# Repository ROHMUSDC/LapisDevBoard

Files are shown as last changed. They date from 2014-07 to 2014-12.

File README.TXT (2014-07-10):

LAPIS DEV BOARD READ ME FILE
Last Updated 7 April 2014

Your New LAPIS Development Board comes pre-loaded with the firmware to allow communication between the custom GUI (Graphical User Interface) and your computer. 
This will allow you to control the state of the I/O pins on the LAPIS DEV BOARD.

Before starting, please review the following:
	1.) 	Read and review this document, and related ReadMe files in each of the sub directories
	2.) 	Read "Introduction to the LAPIS DEV BOARD.pdf" in this same directory
	3.) 	Read the Manual for the LAPIS DEV BOARD, as well as the Manual for the GUI (again, both are in this same directory)
	4.)	Review the manuals for the U8 Development Suite - Becoming familiar with this great suite of tools will be essential to getting the most 
		 out of your LAPIS DEV BOARD! (See: folder titled: "Manuals for the U8 Development Suite")

START UP GUIDE:
	1.)	Install U8 Development Suite on your computer 
		Installation includes “C” compiler, Debugger, Flash Programmer – used to write application code and debug its operation
		Installation also includes all the software manuals for the U8 Development tools
	2.)	Once U8 Development Suite is installed, connect your LAPIS DEV BOARD to your Computer via supplied USB Cable
	3.)	If FTDI drivers need installed to help computer connect to LAPIS DEV BOARD, please do so now. (See Read Me File in FTDI Virtual Com Port Drivers directory)
	4.)	Run the GUI, "LAPIS DEV BOARD_ControlSoftware_3-31-2014_rev01.exe" found in the folder: GUI Program 
	5.) 	Select your COM PORT and click the OPEN PORT Button in the GUI
	6.) 	Click "Test UART" Button in the GUI - The Console Window should now state that the LAPIS DEV BOARD ML610Q112 is connected to your computer

LAPIS DEV BOARD Disk FILE CONTENTS:
	1.) U8 Development Suite Installation CD image - (Compiler, IDE, Debugger, LAPIS U8 Manuals, etc.)
	2.) Data Sheets - Links to download latest Data Sheets
	3.) Express PCB Universal Socket Example - An example of an add-on board for the LAPIS DEV BOARD Platform - 
		Can be used to create custom Plug 'n Play boards for your LAPIS DEV BOARD.
	4.) FTDI Virtual Com Port Drivers - Driver may be needed to allow your LAPIS DEV BOARD to communicate with your Computer. They can be found here if needed.
	5.) GUI Program - Custom Graphical User Interface by Kris Bahar to allow communication between your LAPIS DEV BOARD and your Computer.
	6.) LAPIS DEV BOARD Design Files - Schematics, Board Layout Files, Gerber Files, Bill of Materials, etc. for the LAPIS DEV BOARD
	7.) Pictures for LAPIS DEV BOARD Manual - Various pictures used in LAPIS DEV BOARD Manuals
	8.) SAMPLE Code - Development Code for the LAPIS Semiconductor ML610Q111 & ML610Q112 microcontrollers 
		that can be tested out on this Development Board and to help develop your own applications
		a.) Q111 - 3COLOR_LED_LIGHTING
		b.) Q111 - Quad_Encod_PWM
		c.) Q111 - TEMPLATE
		d.) Q112 - 3COLOR_LED_LIGHTING
		e.) Q112 - Analog
		f.) Q112 - GPIO Complete
		g.) Q112 - PIR ALARM
		h.) Q112 - Quad_Encod_PWM
		i.) Q112 - TEMPLATE
		j.) Q178 - LED_LIGHTING
		k.) UART PAIR (Q111 to Q112 at 512k) (Connect RX of Q111 to TX of Q112 & TX of Q111 to RX of Q112 via 22ohm resistors)
	9.) LAPIS DEV BOARD User Manual (LAPIS DEV BOARD User Manual - Rev 2.7.pdf)
       10.) LAPIS DEV BOARD GUI Manual (LAPIS DEV BOARD GUI Manual - Rev 1.0.pdf)
       11.) Misc. - Contains miscellaneous, LAPIS files.
       12.) Documents:
		a.) Introduction to the LAPIS DEV BOARD.pdf
		b.) Out of Box Guide.pdf
		c.) LAPIS DEV BOARD User Manual - Rev 2.7.pdf
		d.) LAPIS DEV BOARD GUI Manual - Rev 1.0.pdf
		e.) LAPIS DEV BOARD READ ME FILE.TXT

Please contact Carl Schell (cschell@rohmsemiconductor.com) and Alec Melnick (amelnick@rohmsemiconductor.com) for help, support or questions regarding this LAPIS DEV BOARD Kit.

Good Luck in your designs!

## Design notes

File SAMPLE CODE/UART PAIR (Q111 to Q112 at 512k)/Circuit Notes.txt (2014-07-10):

//Circuit Notes:

//Because your LaPi Development Board has 2 independent micros on it, you can easily 
//connect them together and utilize both at the same time!
//
//You will want to connect the TX pin of one micro (say the Q111) to the RX pin
//  of the other (Q112)...and likewise the RX pin of the first micro (Q111) to 
//  the TX of the second (Q112). You can do this on the prototyping area of the
//  LaPi Dev Board.  I put 330 resistors in series for each of the two connections
//  to limit the current.
//
//Once connected, program each micro with the communication code, and they are 
//  now able to communicate at very fast speeds. I had both micros running at
//  512,000 Baud, and communication was fine!

//In this example set, the Q111 micro (MASTER) sends data to the Q112 micro (SLAVE), so they
//are acting as MASTER & SLAVE...but there is no reason, there couldn't be 
//back-and-forth communication...

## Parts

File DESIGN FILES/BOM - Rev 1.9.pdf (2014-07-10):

## LaPi Development Board

CIRCUIT SCHEMATIC | Revision: 1.9
Last Updated | April 10th, 2013 - 17:30
# | Reference | Value | Footprint | Manufacturer | Manufacturer's Part # | Digi-Key Part#

1 | J2 | Voltage Selector | Through-hole - 1x3 | Samtec | HTSW-103-07-G-S | HTSW-103-07-G-S-ND
2 | J5 | Target Micro Selector - TST
3 | J6 | Target Micro Selector - RST
4 | J7 | nanoEase PWR Opt Selector
5 | J12 | MCU Com Selector - RX
6 | J13 | MCU Com Selector - TX
7 | J14 | nanoEase RST Opt Selector
8 | J8 | Debugger | Through-hole - 2x7 | Samtec | TSW-150-07-L-D | SAM1030-50-ND
9 | J9 | Universal Socket #1 | Through-hole - 2x13
10 | J10 | Universal Socket #2 | Through-hole - 2x13
11 | J11 | SMD - micro USB | Surface Mount - microUSB | Hirose | ZX62R-B-5P | H11574CT-ND
12 | J1 | External Power | xxx | xxx | xxx | xxx
13 | J3 | 15 I/O Pins Q111 | xxx | xxx | xxx | xxx
14 | J4 | 25 I/O pins Q112 | xxx | xxx | xxx | xxx
15 | U1 - New | 3.3v LDO Reg (USB 5V to 3.3v, etc.) | Surface Mount - HRP5 (5-pins plus tab) | ROHM | BA33D18HFP | BA33D18HFPDKR-ND
16 | U2 | Q111 - 5V, 8-Bit, 20-pin LAPIS Micro | Surface Mount - TSSOP-20 (20-pin) | ROHM | ML610Q111 | LAPIS-SAMPLES
17 | U3 | Q112 - 5V, 8-Bit, 20-pin LAPIS Micro | Surface Mount - LQFP-32 (32-pin) | ROHM | ML610Q112 | LAPIS-SAMPLES
18 | U4 | Voltage Level Shifter (2-bit) | Surface Mount - DCT (8-pin) | Texas Instruments | TXS0102DCTR | 296-21978-1-ND
19 | U5 | USB-to-UART Translator | Surface Mount - SSOP (16-pin) | FTDI | FT230XS-R | 768-1135-1-ND
20 | S1 - New | Micro's Reset Button (Normally Open) | Surface Mount (2-pad) | E-Switch | TL3302AF180QG | EG2528DKR-ND
21 | LED1 | RED - 5V PWR | SMD 0805 (2012 Metric) | ROHM | SML-210VTT86 | 511-1289-1-ND
22 | LED2 | RED - 3.3V PWR
23 | LED3 | GREEN - RX Indicator | SMD 0805 (2012 Metric) | ROHM | SML-210MTT86 | 511-1287-1-ND
24 | LED4 | YELLOW - TX Indicator | SMD 0805 (2012 Metric) | ROHM | SML-210YTT86 | 511-1290-1-ND
25 | D1 | Schottky Diode Input Protection - 20V 3A | Surface Mount - 123SOD (2-pads) | ROHM | RB051M-2YTR | RB051M-2YCT-ND (http://www.digikey.com/product-detail/en/RB051M-2YTR/RB051M-2YCT-ND/2615726)
26 | FB1 | Ferrite Bead (600R/0.5A) | SMD 0805 (2012 Metric) | Laird | MI0805K601R-10 | 240-2390-1-ND
27 | R1 | 0R | SMD 0805 (2012 Metric) | ROHM | MCR10EZPJ000 | RHM0.0ARCT-ND
28 | R2
29 | R3
30 | R4
31 | R14
32 | R15
33 | R16
34 | R17
35 | R23 | 27R | SMD 0805 (2012 Metric) | ROHM | MCR10EZPF2702 | RHM27.0KCRCT-ND
36 | R24
37 | R6 | 270R | SMD 0805 (2012 Metric) | ROHM | MCR10EZHJ271 | RHM270ACT-ND
38 | R7
39 | R13
40 | R21
41 | R22
42 | R9 | 10k | SMD 0805 (2012 Metric) | ROHM | MCR10EZPF1002 | RHM10.0KCRCT-ND
43 | R10
44 | R11
45 | R12
46 | R20
47 | R18
48 | R25 | 15K | SMD 0805 (2012 Metric) | ROHM | MCR10EZPF1502 | RHM15.0KCRCT-ND
49 | C16 | Cer - 47pF | SMD 0805 (2012 Metric) | Kemet | C0805C470J1GACTU | 399-8079-1-ND
50 | C17
51 | C1 | Cer - 0.01 µF | SMD 0805 (2012 Metric) | TDK Corporation | C2012X7R2E103K | 445-2280-1-ND
52 | C6
53 | C15
54 | C18
55 | C5 | Cer - 0.1 µF | SMD 0805 (2012 Metric) | TDK Corporation | C2012X7R2A104K | 445-1418-1-ND
56 | C10
57 | C11
58 | C13
59 | C14
60 | C19
61 | C3 - New | Polarized - 3.3 µF, 50V | SMD Alum Cap (660x773) | Panasonic | EEE-1HA3R3NP | PCE4303DKR-ND
62 | C12 | Polarized - 4.7 µF | SMD Alum Cap (430x540) | Panasonic | ECE-V1EA4R7SR | PCE3066CT-ND
63 | C2 | Cer - 4.7 µF | SMD 0805 (2012 Metric) | TDK Corporation | C2012Y5V1A475Z/1.25 | 445-1370-1-ND
64 | C7
65 | C4 - New | Cer - 10 µF | SMD 0805 (2012 Metric) | TDK Corporation | C2012X5R1C106K085AC | 445-7644-6-ND
66 | Rubber Feet | 5 per board | Stick-on Rubber Feet | 3M | SJ-5003 (white) | SJ5003-9-ND
67 | Chiclets | 7 per board | Chicle Jumpers with Tab | Sullins Connector Solutions | NPC02SXON-RC | S9341-ND

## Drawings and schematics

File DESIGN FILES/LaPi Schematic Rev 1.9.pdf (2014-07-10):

# INPUT POWER

## For 5.0V to Micro:

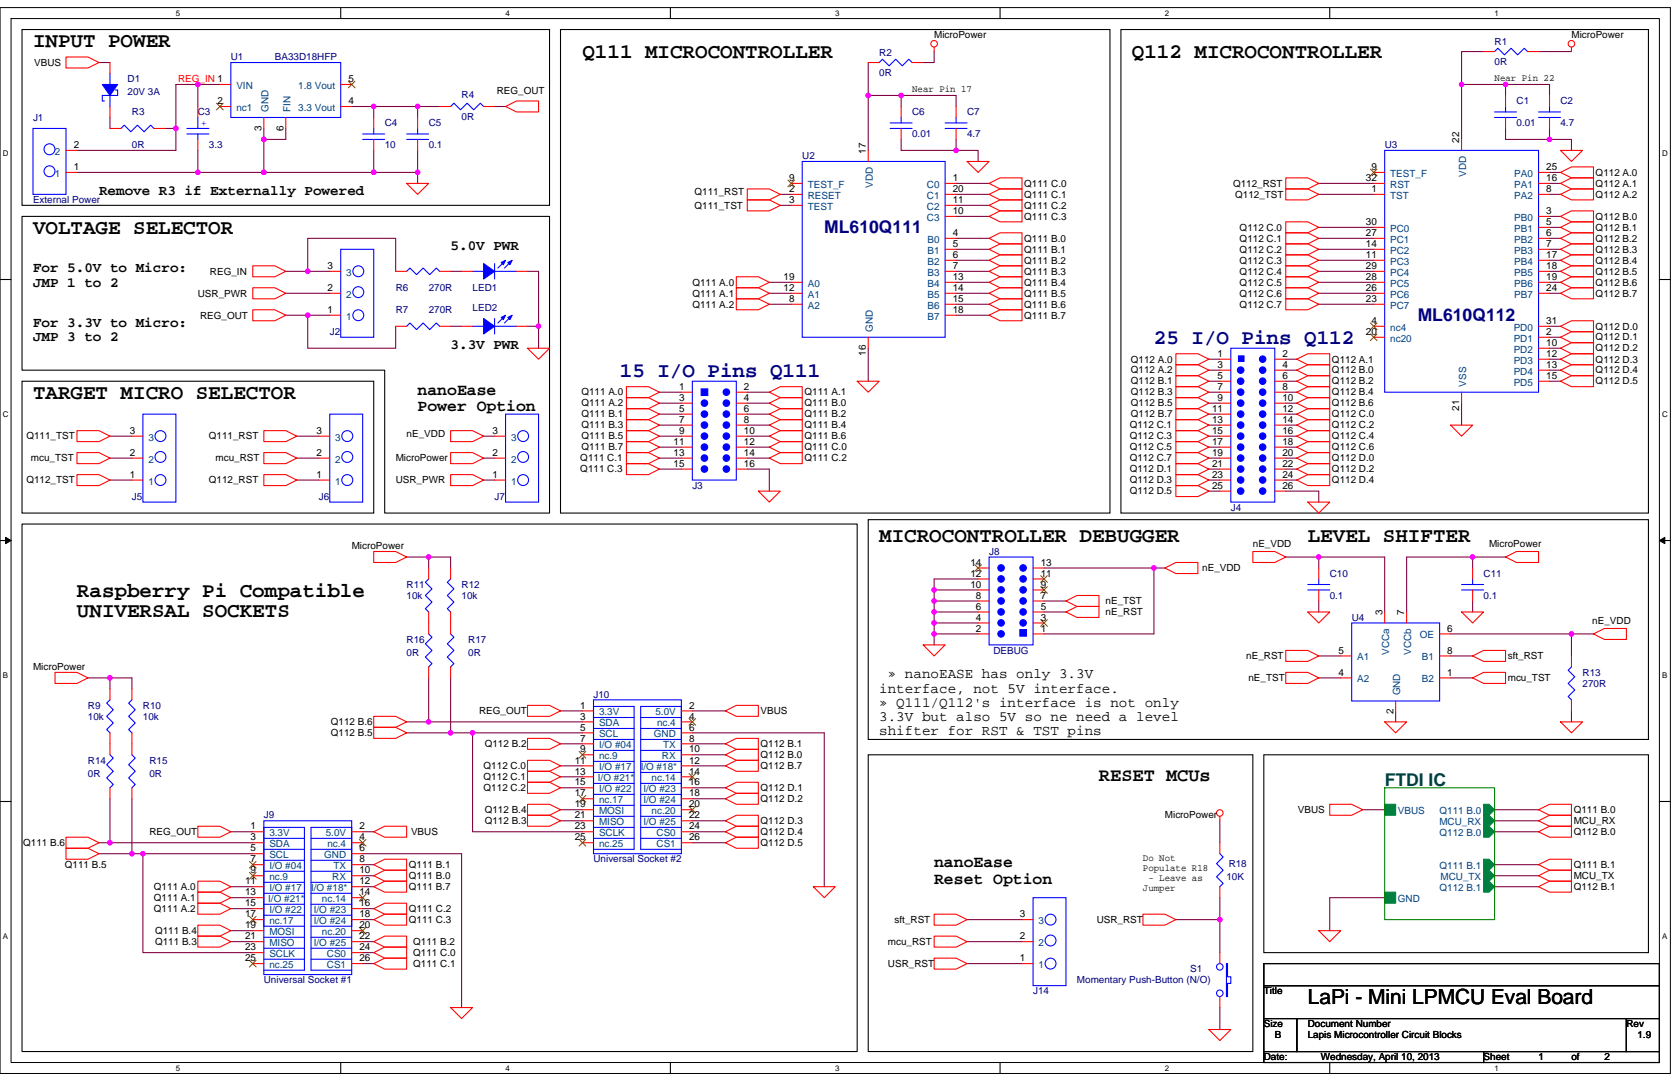
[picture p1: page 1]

Remove R3 if Externally Powered
VOLTAGE SELECTOR

» nanoEASE has only 3.3V
interface, not 5V interface.
» Q111/Q112's interface is not only
3.3V but also 5V so ne need a level
shifter for RST & TST pins

LaPi - Mini LPMCU Eval Board

Size Size Size B B B | Document Number Document Number Document Number Lapis Microcontroller Circuit Blocks Lapis Microcontroller Circuit Blocks Lapis Microcontroller Circuit Blocks | Rev Rev Rev 1.9 1.9 1.9

Date: Date: Date: Wednesday, April 10, 2013 Wednesday, April 10, 2013 Wednesday, April 10, 2013 | Sheet Sheet Sheet 1 1 1 of of of 2 2 2

# USB to serial UART interface

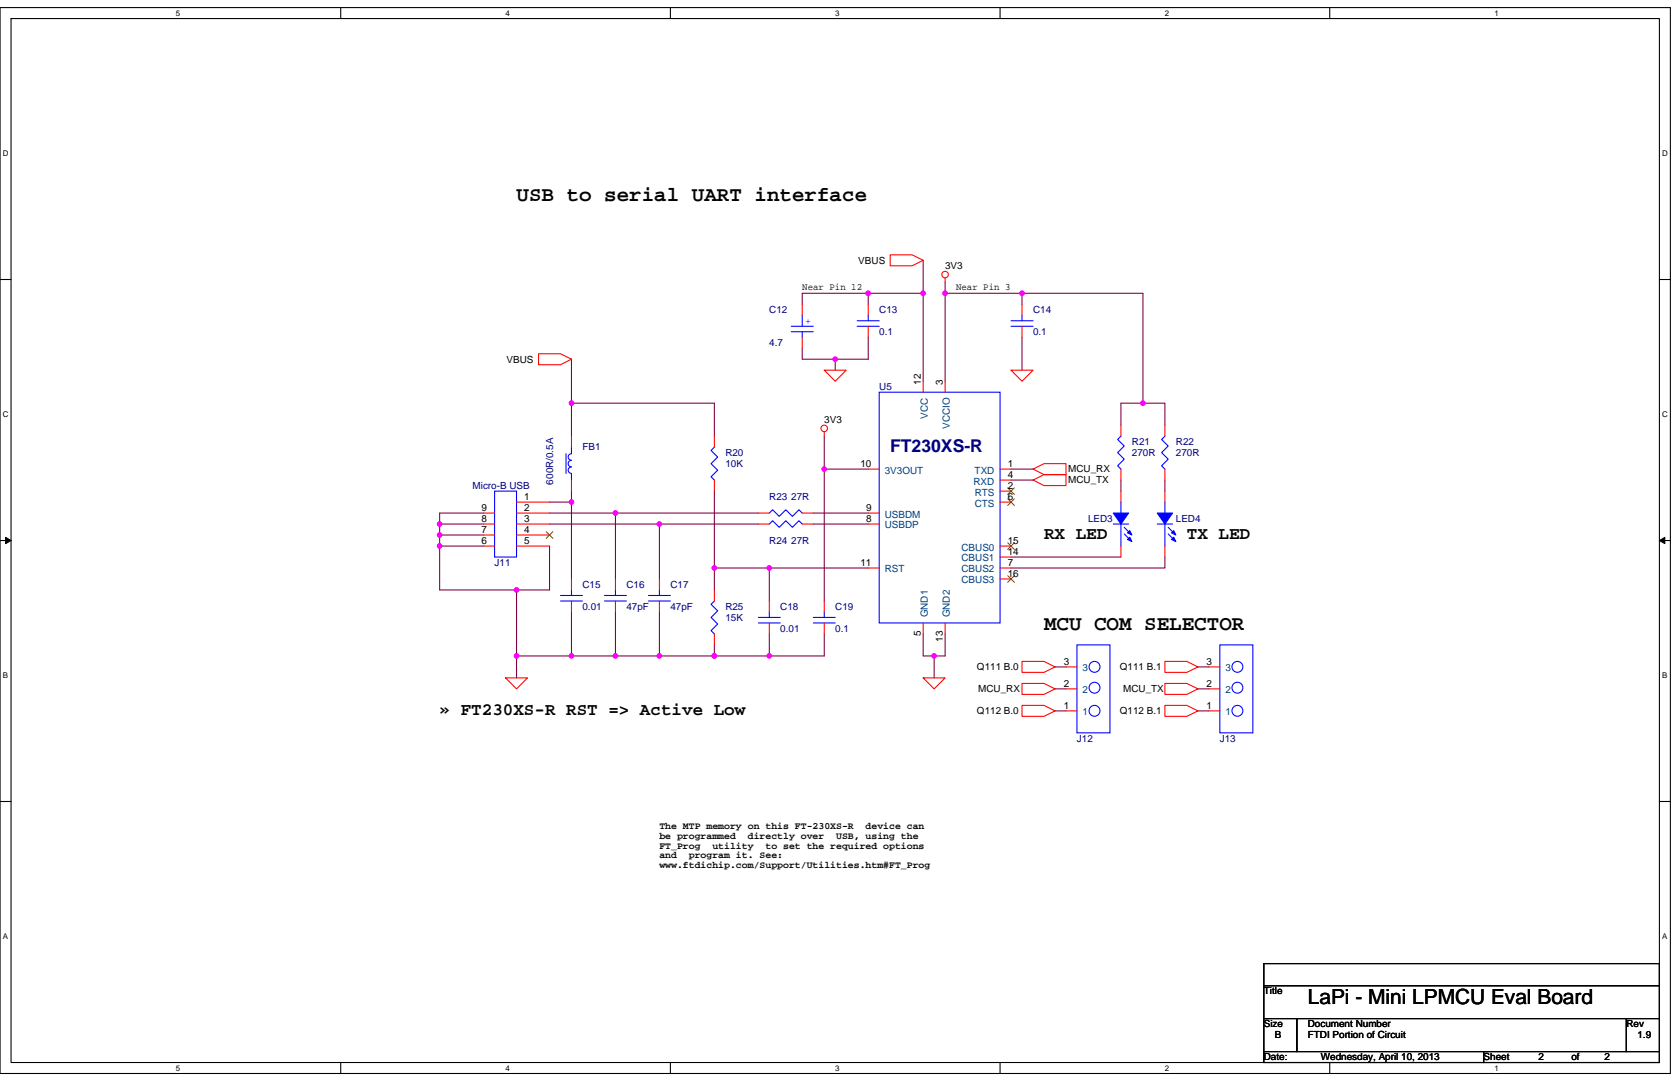
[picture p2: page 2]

The MTP memory on this FT-230XS-R device can
be programmed directly over USB, using the
FT_Prog utility to set the required options
and program it. See:
www.ftdichip.com/Support/Utilities.htm#FT_Prog

LaPi - Mini LPMCU Eval Board

Size Size Size B B B | Document Number Document Number Document Number FTDI Portion of Circuit FTDI Portion of Circuit FTDI Portion of Circuit | Rev Rev Rev 1.9 1.9 1.9

Date: Date: Date: Wednesday, April 10, 2013 Wednesday, April 10, 2013 Wednesday, April 10, 2013 | Sheet Sheet Sheet 2 2 2 of of of 2 2 2

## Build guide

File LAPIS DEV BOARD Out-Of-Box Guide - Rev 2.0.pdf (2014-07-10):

# LaPi Development Kit: “Out-Of-Box Guide”

## Introduction:

Thank you for purchasing our LaPi Development Kit. This LaPi kit will allow you to start creating your own applications using our powerful LAPIS microcontrollers (mcu). This board has 2 re-programmable mcu’s on it, each preprogrammed with firmware that will allow them to communicate out of the box with a simple Graphical User Interface (GUI) that we have developed. The GUI will allow you to plug your LaPi board into your computer over a USB interface, so that you can control any I/O pin on the device, including the UART, GPIOs, and I2C Bus controller.

Here are the 3 Steps to Install,

## Update and start using this system…

1.) Verify that the LaPi Evaluation Board is configured the way you need it.

2.) Review Documentation, Sample Code,
and other useful files on USB Flash
Drive - Connect the LaPi Dev Board to

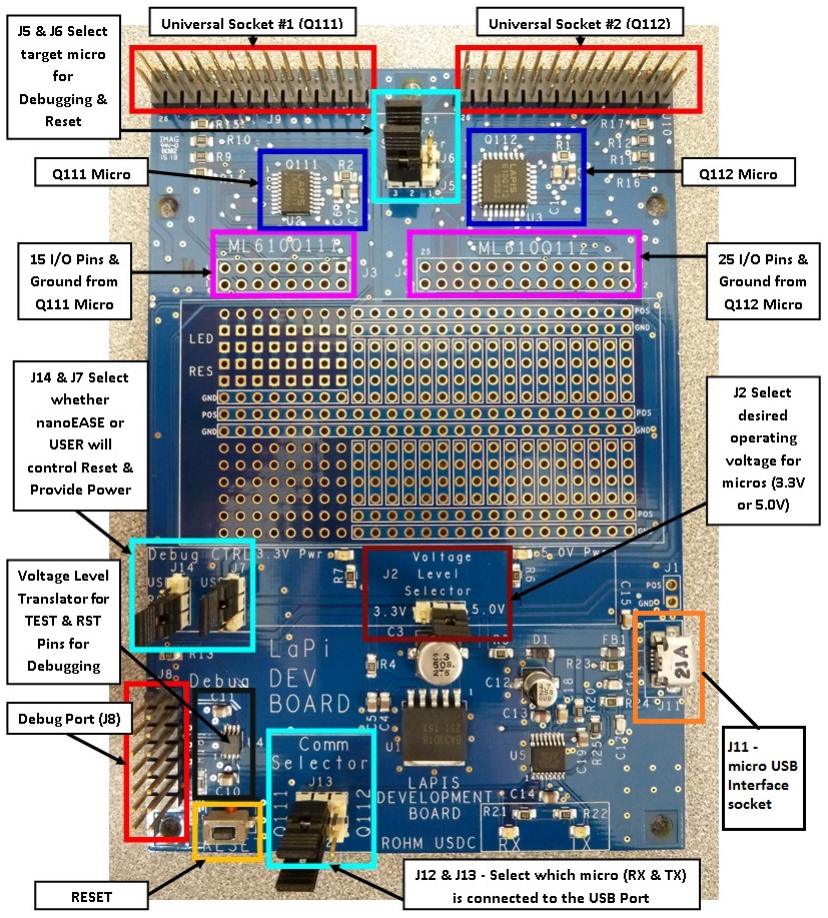
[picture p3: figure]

your computer using a USB cable. The drivers for the USB interface are located in the directory \FTDI Virtual Com Port Drivers. You should copy most of the files from the USB Flash drive to your computer. Run the windows program …\LaPi_StartingSoftware_REV01\LaPi - PC Application\LaPi_ControlSoftware_1-14-2014_rev01.exe to start the GUI communicating with the board. The programs on the mcus will operate with or without the debugger connected to the device.

3.) The code development tool used to write and debug code on the devices are provided on the USB FLASH Drive in the directory \U8 Dev Suite Install File. The tools run on Windows XP, Vista* and 7* (* = 32 (x32) bit or 64(x64) bit versions). You will have to log in as administrator to install in some of these environments.
Refer to Release Note-e.pdf for detailed install directions. To assure that you are using the latest tools register at the LAPIS Semiconductor Low Power Micro Support site: https://www.lapis-semi.com/customer/lpmcu/login.html

The projects that are preprogrammed on the ML610Q111 and 112 devices are located in the directory …\LaPi_StartingSoftware_REV01\LaPi - Q111 - Default Firmware (Release) and …\LaPi_StartingSoftware_REV01\Lapi - Q112 - Default Firmware (Release) respectively. Make sure that the project that you choose corresponds to the device that the GUI is connected to.

To see if new projects are available visit the LaPi Dev Kit section of http://www.rohm.com/web/global/lowpower-microcontroller (http://www.rohm.com/web/global/low-power-microcontroller) or contact LaPiDevKitSupport@rohmsemiconductor.com

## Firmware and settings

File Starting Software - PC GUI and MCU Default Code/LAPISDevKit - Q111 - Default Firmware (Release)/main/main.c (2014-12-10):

//*****************************************************************************
// Program:	 LAPIS Development Board Demo Code Q111
// Author:	 C. Schell & K. Bahar
//		 ROHM Semiconductor USA, LLC
//		 US Design Center
// Started:  April 6th, 2013
// Purpose:	 Demonstration Code for use with Lapis "LAPIS" Development Board 
// Updated:	 October 17th, 2013
//*****************************************************************************

//*****************************************************************************
// Microcontroller's connections on the LAPIS Development Board to the 
//  Plug 'n Play, Raspberry Pi Compatible, Universal Connectors:
//
// ================================ ML610Q111 ================================= 
//
// Pin-01 => 3.3V Power					Pin-02 => 5.0V Power (VBUS)
// Pin-03 => I2C-SDA  (Q111 I/O B.6)	Pin-04 => no connection
// Pin-05 => I2C-SCL  (Q111 I/O B.5)*	Pin-06 => GROUND
// Pin-07 => no connection*				Pin-08 => UART-TX  (Q111 I/O B.1)
// Pin-09 => no connection				Pin-10 => UART-RX  (Q111 I/O B.0) 
// Pin-11 => GPIO #17 (Q111 I/O A.0)	Pin-12 => GPIO #18 (Q111 I/O B.7)
// Pin-13 => GPIO #21 (Q111 I/O A.1)	Pin-14 => no connection
// Pin-15 => GPIO #22 (Q111 I/O A.2)	Pin-16 => GPIO #23 (Q111 I/O C.2)
// Pin-17 => no connection				Pin-18 => GPIO #24 (Q111 I/O C.3)
// Pin-19 => SPI-MOSI (Q111 I/O B.4)	Pin-20 => no connection
// Pin-21 => SPI-MISO (Q111 I/O B.3)	Pin-22 => GPIO #25 (Q111 I/O B.2)
// Pin-23 => SPI-SCLK (Q111 I/O B.5)*	Pin-24 => SPI-CS0  (Q111 I/O C.0)
// Pin-25 => no connection				Pin-26 => SPI-CS1  (Q111 I/O C.1)
//
//=============================================================================
//*****************************************************************************

//*****************************************************************************
// Q111 Microcontroller's I/O Pins at J3 on the LAPIS Development Board to the
// LAPIS Development Board 
//
// ================================ ML610Q111 ================================= 
//
// Pin-01 => A.0				Pin-02 => A.1
// Pin-03 => A.2				Pin-04 => B.0
// Pin-05 => B.1				Pin-06 => B.2
// Pin-07 => B.3				Pin-08 => B.4
// Pin-09 => B.5				Pin-10 => B.6 
// Pin-11 => B.7				Pin-12 => C.0
// Pin-13 => C.1				Pin-14 => C.2
// Pin-15 => C.3				Pin-16 => GROUND
//
//=============================================================================
//*****************************************************************************

//***** PREPROCESSOR DIRECTIVES ***********************************************
 // INCLUDED FILES...
	#include	<ML610111.H>	// Lapis Micro ML610Q111 on LAPIS Development Board
	//#include	<ctype.h>		// Character classification and conversion 
	//#include	<errno.h>		// Error identifiers Library
	//#include	<float.h>		// Numerical limits for floating-point numbers
	//#include	<limits.h>		// Numerical limits for integers
	//#include	<math.h>		// Mathematical functions
	//#include	<muldivu8.h>	// Multiplication and Division accelerator
	//#include	<setjmp.h>		// Global jump (longjmp)
	//#include	<signal.h>		// Signal handling functions
	//#include	<stdarg.h>		// Variable numbers of arguments
	//#include	<stddef.h>		// Standard types and macros 
	#include	<stdio.h>		// I/O-related processing
	#include	<stdlib.h>		// General-purpose utilities
	//#include	<string.h>		// Character string manipulation routines
	//#include	<yfuns.h>		// 
	//#include	<yvals.h>		// Called for by most Header Files
	#include 	<uart.h>		// UART Function Prototypes
	#include 	<common.h>		// Common Definitions
	#include 	<mcu.h>		// MCU Definition
	#include 	<irq.h>		// IRQ Definitions
	#include	"i2c.h"		// I2C Definition
	//#include 	<main.h>		// Clear WDT API
	//#include 	<clock.h>		// Set System Clock API
	//#include 	<tbc.h>		// Set TBC (Timer Based Clock) API
	//#include 	<timer.h>		// Timer Macros & APIs

//*****************************************************************************
 // I/O PIN DATA ALIASES...
// Connections for Q111 Universal Socket
	#define RX 		PB0D 
	#define TX 		PB1D
	#define I2C_SDA 	PB6D 
	#define I2C_SCL 	PB5D 
	#define GPIO_17	PA0D
	#define GPIO_21	PA1D
	#define GPIO_22	PA2D
	#define GPIO_18	PB7D
	#define GPIO_23	PC2D
	#define GPIO_24	PC3D
	#define GPIO_25	PB2D
	#define SPI_MOSI	PB4D
	#define SPI_MISO	PB3D
	#define SPI_SCL 	PB5D
	#define SPI_CS0		PC0D
	#define SPI_CS1 	PC1D 	

//*****************************************************************************
//===========================================================================
//   MACROS: 
//===========================================================================
// ===== Serial Strings =====
#define WelcomeString		( "LAPIS Q111 LAPIS DEV. DEMO") 
#define WelcomeString_LEN	( sizeof(WelcomeString) - 1 )

// ===== Peripheral setting.=====
#define HSCLK_KHZ	( 8000u )	// 8MHz = 8000kHz (will be multiplied by 1024 to give 8,192,000Hz)
#define FLG_SET	( 0x01u ) 

// ===== SET DESIRED UART SETTINGS HERE! (Options in UART.h) =====
	#define UART_BAUDRATE		( UART_BR_9600BPS) 	// Data Bits Per Second - Tested at rates from 2400bps to 512000bps!
	#define UART_DATA_LENGTH	( UART_LG_8BIT )		// x-Bit Data
	#define UART_PARITY_BIT		( UART_PT_NON )		// Parity
	#define UART_STOP_BIT		( UART_STP_1BIT )		// x Stop-Bits
	#define UART_LOGIC			( UART_NEG_POS )		// Desired Logic
	#define UART_DIRECTION		( UART_DIR_LSB )		// LSB or MSB First

//*****************************************************************************

//*****************************************************************************
//===========================================================================
//   STRUCTURES: 
//===========================================================================
//Example Structure Declaration
typedef struct {
	unsigned char state     : 1;
	unsigned char state_sub : 2;
	unsigned char reserve   : 5;
} STRUCT_STATE;	

static const tUartSetParam  _uartSetParam = {		// UART Parameters
	UART_BAUDRATE,						// Members of Structure...
	UART_DATA_LENGTH,						// Members of Structure...
	UART_PARITY_BIT,						// Members of Structure...
	UART_STOP_BIT,						// Members of Structure...
	UART_LOGIC,							// Members of Structure...
	UART_DIRECTION						// Members of Structure...
};

//*****************************************************************************


//*****************************************************************************
//===========================================================================
//   FUNCTION PROTOTYPES: 
//	Establishes the name and return type of a function and may specify the 
// 	types, formal parameter names and number of arguments to the function                                 
//===========================================================================
void main_clrWDT( void );			// no return value and no arguments
//void Alarm( void );				// no return value and no arguments
void Initialization( void );			// no return value and no arguments
void SetOSC( void );				// no return value and no arguments
void analog_comparator( void );		// no return value and no arguments
void PortA_Low( void );				// no return value and no arguments
void PortB_Low( void );				// no return value and no arguments
void PortC_Low( void );				// no return value and no arguments
void PortA_Digital_Inputs( void );		// no return value and no arguments
void PinB0_PWM( void ); 			// no return value and no arguments

void _funcUartFin( unsigned int size, unsigned char errStat );
void _funcI2CFin( unsigned int size, unsigned char errStat );
void checkI2C( void );
void main_reqNotHalt( void );
void _intUart( void );
void _intI2c( void );
void NOP1000( void );

//*****************************************************************************

//GLOBALS...
unsigned char	_flgUartFin;
unsigned char 	_flgI2CFin;
unsigned char	_reqNotHalt;

unsigned char	HelloWorld[14] = {"Hello World!  "};

unsigned char	InputStatus[23] = {"INP_00000000_00000000"};	//Used for Testing the UART Terminal during initial
unsigned char	InputRec[14] = {"INP Received"};				//Used for Testing the UART Terminal during initial
unsigned char	OutputRec[23] = {"OUT Received         "};		//Used for Testing the UART Terminal during initial
unsigned char	RecWorld[21];									//Used for Testing the UART Terminal during initial
unsigned char	AckMCUConn[22] = {"ML610Q111 Connected!"};
unsigned char	ListFWRev[22] = {"Firmware Version: 01"};
unsigned char	NackMCUConn[62] = {"Please Close Port and change Target MCU under Device Options"};
unsigned char	I2C_TX_REC[21] = {"I2CTX CMD Received!"};
unsigned char	I2C_RX_REC[21] = {"I2CRX CMD Received!"};
unsigned char	I2C_RX_Data[23] = {"I2C-R X X X X X X X X"};

unsigned int	UART_VAR;

static unsigned char			I2C_BUFF[46];
static unsigned char			I2CAdd;
static unsigned char			I2CNumBytes;
static unsigned char			Data0Str;
static unsigned char			Data1Str;
static unsigned char			Data2Str;
static unsigned char			Data3Str;
static unsigned char			Data4Str;
static unsigned char			Data5Str;
static unsigned char			Data6Str;
static unsigned char			Data7Str;
static unsigned char			RegAddr;
static unsigned char			I2CAdd_temp;
static unsigned char			I2CNumBytes_temp;
static unsigned char			Data0Str_temp;
static unsigned char			Data1Str_temp;
static unsigned char			Data2Str_temp;
static unsigned char			Data3Str_temp;
static unsigned char			Data4Str_temp;
static unsigned char			Data5Str_temp;
static unsigned char			Data6Str_temp;
static unsigned char			Data7Str_temp;
static unsigned char			RegAddr_temp;
static unsigned char			I2CSendInfo[8];
static unsigned char			I2CReceInfo[8];
static unsigned char			chari;
static unsigned char			charj;
static unsigned char			chark;

unsigned int ret;
unsigned int testI2C;

/*############################################################################*/
/*#                                  APIs                                    #*/
/*############################################################################*/
//*****************************************************************************
//===========================================================================
//  	Start of MAIN FUNCTION
//===========================================================================
int main(void) 
{

char char_a;			// -128 to 127
unsigned char uchar;		// 0-255
int inta, table [100];		// -32,768 to 32767
unsigned int uint;	// 0 to 65,535
long long_a, delay;			// -2,147,483,648 to 2,147,483,647
float float_a;			// 1.17549435e-38 to 3.40282347e+38
double double_a;			// 2.2250738585072014e-308 to 1.7976931348623157e+308 


//unsigned char encoder_position, previous_encoder_position;  // 0-255
unsigned char button_flag;  						// 0-255
int i,j,k,x,y;								// -32,768 to 32767
unsigned char sndByte;
unsigned int count;
char maskC;

Init:
	Initialization();		//Ports, UART, Timers, Oscillator, Comparators, etc.

RX_Loop:
		main_clrWDT();
		
		//Reset RecWorld for UART Receive
		for (i=0;i<22;i++)
		{
			RecWorld[i] = 0;	
		}
		
		//Begin UART Receive
		_flgUartFin = 0;
		uart_stop();
		uart_startReceive(RecWorld, 21, _funcUartFin);
		while(_flgUartFin != 1){
			NOP1000();
			main_clrWDT();
		}
		
		//Check UART Receive String for "ACK"
		//if ACK Sent, Return "UART Connected"
		//--This loop triggers when COM port is open3ed on PC
		if(RecWorld[0] == 0x41){			//if RECWORLD == "ACK1"
			if(RecWorld[1] == 0x43){
				if(RecWorld[2] == 0x4B){
					if(RecWorld[3] == 0x31){
						_flgUartFin = 0;
						uart_stop();
						uart_startSend(AckMCUConn, 22, _funcUartFin);
						while(_flgUartFin != 1){
							NOP1000();
							main_clrWDT();
						}
						_flgUartFin = 0;
						uart_stop();
						uart_startSend(ListFWRev, 22, _funcUartFin);
						while(_flgUartFin != 1){
							NOP1000();
							main_clrWDT();
						}
					}
					else
					{
						_flgUartFin = 0;
						uart_stop();
						uart_startSend(NackMCUConn, 62, _funcUartFin);
						while(_flgUartFin != 1){
							NOP1000();
							main_clrWDT();
						}
						
					}
				}
			}
		}
		
		//Check UART Receive String for "INC" - Input, Port C
		//This section is triggered by the GPIO command tab
		if(RecWorld[0] == 0x49){			//if RECWORLD == "INC"
			if(RecWorld[1] == 0x4E){
				if(RecWorld[2] == 0x43){
					InputStatus[2] = 0x43;
					InputRec[2] = 0x43;
					for(count = 4; count < 12; count++)
					{ 
						RecWorld[count] -= 0x30;
						if(RecWorld[count] != (0x01||0x00)){
							RecWorld[count] = 0;
						}
					}
					
					//Set PORTC to Input or Output based on PC application
					//PC7DIR = RecWorld[4];
					//PC6DIR = RecWorld[5];
					//PC5DIR = RecWorld[6];
					//PC4DIR = RecWorld[7];
					PC3DIR = RecWorld[8];
					PC2DIR = RecWorld[9];
					PC1DIR = RecWorld[10];
					PC0DIR = RecWorld[11];
					
					//Format I/O Direction into output string
					InputStatus[4] = 0x78;
					InputStatus[5] = 0x78;
					InputStatus[6] = 0x78;
					InputStatus[7] = 0x78;
					InputStatus[8] = PC3DIR + 0x30;
					InputStatus[9] = PC2DIR + 0x30;
					InputStatus[10] = PC1DIR + 0x30;
					InputStatus[11] = PC0DIR + 0x30;
					
					//Format I/O Level into output string
					InputStatus[13] = 0x78;
					InputStatus[14] = 0x78;
					InputStatus[15] = 0x78;
					InputStatus[16] = 0x78;
					InputStatus[17] = PC3D + 0x30;
					InputStatus[18] = PC2D + 0x30;
					InputStatus[19] = PC1D + 0x30;
					InputStatus[20] = PC0D + 0x30;
					
					//Send the InputStatus String
					//	"INP_[PC7DIR][PC6DIR]...[PC0DIR]_[PC7D]{PC6D]...[PC0D]"
					_flgUartFin = 0;
					uart_stop();
					uart_startSend(InputStatus, 23, _funcUartFin);
					while(_flgUartFin != 1){
						NOP1000();
						main_clrWDT();
					}
					
					//Send the Acknowledgement String
					_flgUartFin = 0;
					uart_stop();
					uart_startSend(InputRec, 14, _funcUartFin);
					while(_flgUartFin != 1){
						NOP1000();
						main_clrWDT();
					}
				}
			}
		}
		
		//Check UART Receive String for "OUC" - Output, PortC
		//This section is triggered by the GPIO command tab
		if(RecWorld[0] == 0x4F){			//if RECWORLD == "OUC"
			if(RecWorld[1] == 0x55){
				if(RecWorld[2] == 0x43){
					OutputRec[2] = 0x43;
					for(count = 4; count < 21; count++)
					{ 
						RecWorld[count] -= 0x30;
						if(RecWorld[count] != (0x01||0x00)){
							RecWorld[count] = 0;
						}
					}
					//Set I/O Pin Direction based on PC App
					//PC7DIR = RecWorld[4];
					//PC6DIR = RecWorld[5];
					//PC5DIR = RecWorld[6];
					//PC4DIR = RecWorld[7];
					PC3DIR = RecWorld[8];
					PC2DIR = RecWorld[9];
					PC1DIR = RecWorld[10];
					PC0DIR = RecWorld[11];
					
					//Set I/O Pin Direction based on PC App
					//PC7D = RecWorld[13];
					//PC6D = RecWorld[14];
					//PC5D = RecWorld[15];
					//PC4D = RecWorld[16];
					PC3D = RecWorld[17];
					PC2D = RecWorld[18];
					PC1D = RecWorld[19];
					PC0D = RecWorld[20];
					
					//Return GPIO pin state within the acknowledgement string
					//OutputRec[13] = PC7D + 0x30;
					//OutputRec[14] = PC6D + 0x30;
					//OutputRec[15] = PC5D + 0x30;
					//OutputRec[16] = PC4D + 0x30;
					OutputRec[17] = PC3D + 0x30;
					OutputRec[18] = PC2D + 0x30;
					OutputRec[19] = PC1D + 0x30;
					OutputRec[20] = PC0D + 0x30;
					
					_flgUartFin = 0;
					uart_stop();
					uart_startSend(OutputRec, 23, _funcUartFin);
					while(_flgUartFin != 1){
						NOP1000();
						main_clrWDT();
					}
				}
			}
		}
		
		//Check UART Receive String for "INB" - Input, PortB
		//This section is triggered by the GPIO command tab
		if(RecWorld[0] == 0x49){			//if RECWORLD == "INB"
			if(RecWorld[1] == 0x4E){
				if(RecWorld[2] == 0x42){
					InputStatus[2] = 0x42;
					InputRec[2] = 0x42;
					for(count = 4; count < 12; count++)
					{ 
						RecWorld[count] -= 0x30;
						if(RecWorld[count] != (0x01||0x00)){
							RecWorld[count] = 0;
						}
					}
					
					//For Port C GPIO, we can only control two GPIOs due to
					//other functionality.  Please see comments below
					
					//Set PORTC to Input or Output based on PC application
					PB7DIR = RecWorld[4]; 
					//PC6DIR = RecWorld[5];		//I2C SDA
					//PC5DIR = RecWorld[6];		//SPI SCLK/I2C SCL
					//PC4DIR = RecWorld[7];		//SPI MOSI
					//PC3DIR = RecWorld[8];		//SPI MISO
					PB2DIR = RecWorld[9];
					//PC1DIR = RecWorld[10];	//UART TX
					//PC0DIR = RecWorld[11];	//UART RX
					
					//Format I/O Direction into output string
					InputStatus[4] = PB7DIR + 0x30;
					InputStatus[5] = 0x78;
					InputStatus[6] = 0x78;
					InputStatus[7] = 0x78;
					InputStatus[8] = 0x78;
					InputStatus[9] = PB2DIR + 0x30;
					InputStatus[10] = 0x78;
					InputStatus[11] = 0x78;
					
					//Format I/O Level into output string
					InputStatus[13] = PB7D + 0x30;
					InputStatus[14] = 0x78;
					InputStatus[15] = 0x78;
					InputStatus[16] = 0x78;
					InputStatus[17] = 0x78;
					InputStatus[18] = PB2D + 0x30;
					InputStatus[19] = 0x78;
					InputStatus[20] = 0x78;
					
					//Send the InputStatus String
					//	"INB_[PC7DIR][PC6DIR]...[PC0DIR]_[PC7D]{PC6D]...[PC0D]"
					_flgUartFin = 0;
					uart_stop();
					uart_startSend(InputStatus, 23, _funcUartFin);
					while(_flgUartFin != 1){
						NOP1000();
						main_clrWDT();
					}
					
					//Send the Acknowledgement String
					_flgUartFin = 0;
					uart_stop();
					uart_startSend(InputRec, 14, _funcUartFin);
					while(_flgUartFin != 1){
						NOP1000();
						main_clrWDT();
					}
				}
			}
		}
		
		//Check UART Receive String for "OUB" - Output, PortB
		//This section is triggered by the GPIO command tab
		if(RecWorld[0] == 0x4F){			//if RECWORLD == "OUB"
			if(RecWorld[1] == 0x55){
				if(RecWorld[2] == 0x42){
					OutputRec[2] = 0x42;
					for(count = 4; count < 21; count++)
					{ 
						RecWorld[count] -= 0x30;
						if(RecWorld[count] != (0x01||0x00)){
							RecWorld[count] = 0;
						}
					}
					//Set I/O Pin Direction based on PC App
					PB7DIR = RecWorld[4];
					//PB6DIR = RecWorld[5];
					//PB5DIR = RecWorld[6];
					//PB4DIR = RecWorld[7];
					//PB3DIR = RecWorld[8];
					PB2DIR = RecWorld[9];
					//PB1DIR = RecWorld[10];
					//PB0DIR = RecWorld[11];
					
					//Set I/O Pin Direction based on PC App
					PB7D = RecWorld[13];
					//PB6D = RecWorld[14];
					//PB5D = RecWorld[15];
					//PB4D = RecWorld[16];
					//PB3D = RecWorld[17];
					PB2D = RecWorld[18];
					//PB1D = RecWorld[19];
					//PB0D = RecWorld[20];
					
					//Return GPIO pin state within the acknowledgement string
					OutputRec[13] = PB7D + 0x30;
					OutputRec[14] = 0x78;
					OutputRec[15] = 0x78;
					OutputRec[16] = 0x78;
					OutputRec[17] = 0x78;
					OutputRec[18] = PB2D + 0x30;
					OutputRec[19] = 0x78;
					OutputRec[20] = 0x78;
					
					_flgUartFin = 0;
					uart_stop();
					uart_startSend(OutputRec, 23, _funcUartFin);
					while(_flgUartFin != 1){
						NOP1000();
						main_clrWDT();
					}
				}
			}
		}
				
		//Start I2C Write Sequence
		//This section is triggered by the write portion of the I2C command tab
		if(RecWorld[0] == 0x49){			//if RECWORLD == "I2CTX"
			if(RecWorld[1] == 0x32){
				if(RecWorld[2] == 0x43){
					if(RecWorld[3] == 0x54){
						if(RecWorld[4] == 0x58){
							//if RECWORLD = "I2CTX" then begin waiting for the I2C sequence to be sent
							// The Sequence will be stored in I2C_BUFF
							_flgUartFin = 0;
							uart_stop();
							uart_startReceive(I2C_BUFF, 46, _funcUartFin);
							while(_flgUartFin != 1){
								NOP1000();
								main_clrWDT();
							}
							
							//This next section will begin parsing the character string into their respective values
							chari = 2;
							charj = 0;
							chark = 0;
							while(I2C_BUFF[chari]!=0x20){
								chari++;
								charj++;
							}
							for(chark = charj; chark>0; chark--){
								if(chark == 3){I2CAdd_temp = (I2C_BUFF[chari-chark]-0x30)*100;}
								else if(chark == 2){I2CAdd_temp = (I2C_BUFF[chari-chark]-0x30)*10;}
								else {I2CAdd_temp = (I2C_BUFF[chari-chark]-0x30);}
								I2CAdd += I2CAdd_temp;
							}
							chari++;
							charj = 0;
							while(I2C_BUFF[chari]!=0x20){
								chari++;
								charj++;
							}
							for(chark = charj; chark>0; chark--){
								if(chark == 3){I2CNumBytes_temp = (I2C_BUFF[chari-chark]-0x30)*100;}
								else if(chark == 2){I2CNumBytes_temp = (I2C_BUFF[chari-chark]-0x30)*10;}
								else {I2CNumBytes_temp = (I2C_BUFF[chari-chark]-0x30);}
								I2CNumBytes += I2CNumBytes_temp;
							}
							chari++;
							charj = 0;
							
							while(I2C_BUFF[chari]!=0x20){
								chari++;
								charj++;
							}
							for(chark = charj; chark>0; chark--){
								if(chark == 3){Data0Str_temp = (I2C_BUFF[chari-chark]-0x30)*100;}
								else if(chark == 2){Data0Str_temp = (I2C_BUFF[chari-chark]-0x30)*10;}
								else {Data0Str_temp = (I2C_BUFF[chari-chark]-0x30);}
								Data0Str += Data0Str_temp;
							}
							chari++;
							charj = 0;
							
							while(I2C_BUFF[chari]!=0x20){
								chari++;
								charj++;
							}
							for(chark = charj; chark>0; chark--){
								if(chark == 3){Data1Str_temp = (I2C_BUFF[chari-chark]-0x30)*100;}
								else if(chark == 2){Data1Str_temp = (I2C_BUFF[chari-chark]-0x30)*10;}
								else {Data1Str_temp = (I2C_BUFF[chari-chark]-0x30);}
								Data1Str += Data1Str_temp;
							}
							chari++;
							charj = 0;

							while(I2C_BUFF[chari]!=0x20){
								chari++;
								charj++;
							}
							for(chark = charj; chark>0; chark--){
								if(chark == 3){Data2Str_temp = (I2C_BUFF[chari-chark]-0x30)*100;}
								else if(chark == 2){Data2Str_temp = (I2C_BUFF[chari-chark]-0x30)*10;}
								else {Data2Str_temp = (I2C_BUFF[chari-chark]-0x30);}
								Data2Str += Data2Str_temp;
							}
							chari++;
							charj = 0;
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

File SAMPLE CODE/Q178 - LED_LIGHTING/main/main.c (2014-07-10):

/******************************************************************************
	main.c

    Copyright (C) 2012 LAPIS Semiconductor Co., Ltd.
    All rights reserved.

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
    History
    2012.10.12  ver.1.00
******************************************************************************/
#include "common.h"
#include "mcu.h"
#include "irq.h"
#include "clock.h"
#include "tbc.h"
#include "timer.h"
#include "main.h"
#include "uart.h"
#include "volume.h"
#include "led.h"


/*############################################################################*/
/*#                                  Macro                                   #*/
/*############################################################################*/

/*--- State ---*/
#define	STATE_COLOR			( 0u )
#define	STATE_NIGHT			( 1u )

/*--- Sub State (Color) ---*/
#define	STATE_COLOR_NATURAL	( 0u )
#define	STATE_COLOR_BULB		( 1u )
#define	STATE_COLOR_MIXED		( 2u )

#define	BZR_STATE_CHANGE		( 2u ) // 
#define	BZR_PLUSMINUS		( 1u ) // 
#define	BZR_PLUSMINUS_LIMIT	( 4u ) // 

#define BZR_HZ				( 2500UL )
//#define BZR_HALF_HZ			( BZR_HZ / 2 ) // 
#define BZR_HALF_HZ			( BZR_HZ * 2 )  // 20120928

#define	SW_NONE			( 0u )
#define	SW_COLOR			( 1u )
#define	SW_NIGHT			( 2u )
#define	SW_PLUS			( 3u )
#define	SW_MINUS			( 4u )


#define	STR_NUM			( 42 ) // "state: natural white color, step: 20 max\n\r"

#define	STR_BASE1			( "state: " )
#define	STR_BASE2			( ", step: " )
#define	STR_NEWLINE			( "\n\r" )

#define	STR_BASE1_NUM		( sizeof(STR_BASE1) - 1 )   // null
#define	STR_BASE2_NUM		( sizeof(STR_BASE2) - 1 )   // null
#define	STR_NEWLINE_NUM		( sizeof(STR_NEWLINE) - 1 ) // null

#define	STR_STATE_NATURAL		( "natural white color" )
#define	STR_STATE_BULB		( "light bulb color" )
#define	STR_STATE_MIXED		( "mixed color" )
#define	STR_STATE_NIGHT		( "night light" )

#define	STR_STATE_NATURAL_NUM	( sizeof(STR_STATE_NATURAL) - 1 ) // null
#define	STR_STATE_BULB_NUM	( sizeof(STR_STATE_BULB) - 1 )    // null
#define	STR_STATE_MIXED_NUM	( sizeof(STR_STATE_MIXED) - 1 )   // null
#define	STR_STATE_NIGHT_NUM	( sizeof(STR_STATE_NIGHT) - 1 )   // null

#define	STR_STEP_NUM		( 2 ) // 

#define	STR_MAX			( " max" )
#define	STR_MAX_NUM			( sizeof(STR_MAX) - 1 )   // null

#define	DEBUG
#ifdef 	DEBUG
#define	STR_INIT			( "*** LED LIGHTING DEMO ***\n\r" )
#define	STR_INIT_NUM		( sizeof(STR_INIT) - 1 )  // null
#endif // DEBUG

#define INTERVAL_HZ			( 100UL ) // 100Hz == 10ms/cycle


/*############################################################################*/
/*#                               Structure                                  #*/
/*############################################################################*/


typedef struct {
	unsigned char state     : 1;
	unsigned char state_sub : 2;
	unsigned char reserve   : 5;
} STRUCT_STATE;


/*############################################################################*/
/*#                                Variable                                  #*/
/*############################################################################*/

#ifdef HTBC_HZ

static const unsigned short _valBzrHalfCycle = (unsigned short)( (HTBC_HZ/BZR_HALF_HZ)-1 );

static const unsigned short _valIntervalCycle = (unsigned short)( (HTBC_HZ/INTERVAL_HZ)-1 );

#else // ifdef HTBC_HZ
 #error 'HTBC_HZ' is not defined.
#endif // HTBC_HZ


static STRUCT_STATE _state = {
	STATE_COLOR, STATE_COLOR_NATURAL, 0
};

static unsigned char _swInput = SW_NONE;

static unsigned char _bzrCount = 0;

static unsigned char _IntervalFlag = FALSE;


/*############################################################################*/
/*#                               Prototype                                  #*/
/*############################################################################*/
static void _initPeri( void );
static void _initState( void );

static void _intP00( void );
static void _intP01( void );
static void _intP02( void );
static void _intP03( void );
static void _intTM1( void );
static void _intTM9( void );
static void _intT16H( void );


static void _swInit( void );

static void _bzrInit( void );
static void _bzrStart( unsigned char num );
static void _bzrOperate( void );

static void _IntervalInit( void );
static void _IntervalStart( void );
static void _IntervalStop( void );

static void _stateColorNatural( void );
static void _stateColorBulb( void );
static void _stateColorMixed( void );
static void _stateNightLight( void );

static void _changeNextState( void );
static void _changeNextStateColor( void );

static void _sendStr( void );


/*############################################################################*/
/*#                                  API                                     #*/
/*############################################################################*/

/*******************************************************************************
	Routine Name:	main
	Form:			int main( void )
	Parameters:		void
	Return value:	int
	Description:	main
*******************************************************************************/
int main( void )
{
	/*=== Main initialize. ===*/
	/*--- Peripheral. ---*/
	_initPeri();

#ifdef DEBUG
	/*--- message send ---*/
	uartSendStr( STR_INIT, (unsigned char)STR_INIT_NUM );
#endif // DEBUG

	/*--- State. ---*/
	_initState();

	/*=== Main loop. ===*/
	for (;;)
	{
		/*=== Clear WDT. ===*/
		main_clrWDT();

		if( _state.state == STATE_COLOR )
		{
			switch( _state.state_sub )
			{
				case STATE_COLOR_NATURAL:
					_stateColorNatural();
					break;
				case STATE_COLOR_BULB:
					_stateColorBulb();
					break;
				case STATE_COLOR_MIXED:
					_stateColorMixed();
					break;
				default:
					_initState();
					break;
			}
		}
		else if( _state.state == STATE_NIGHT )
		{
			_stateNightLight();
		}
	}

	return 0;
}

/*******************************************************************************
	Routine Name:	main_clrWDT
	Form:			void main_clrWDT( void )
	Parameters:		void
	Return value:	void
	Description:	clear WDT.
*******************************************************************************/
void main_clrWDT( void )
{
	do {
		WDTCON = 0x5Au;
	} while (WDP != 1);
	WDTCON = 0xA5u;
}

/*############################################################################*/
/*#                              Subroutine                                  #*/
/*############################################################################*/
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
